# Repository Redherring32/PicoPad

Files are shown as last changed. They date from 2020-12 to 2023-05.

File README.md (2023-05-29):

# PicoPad
The world's smallest functional NES controller

## Repository Structure:
* Board Files: Contains all files necessary to open the project in KiCad, as well as the schematic and schematic symbols

* 3D-CAD: Contains the source CAD files for the housing design

* PicoPad.pretty: Library of all the custom footprints used on the board

PicoPad

## License:
Licensed under the TAPR Open Hardware License (www.tapr.org/OHL)

©Redherring32 2020

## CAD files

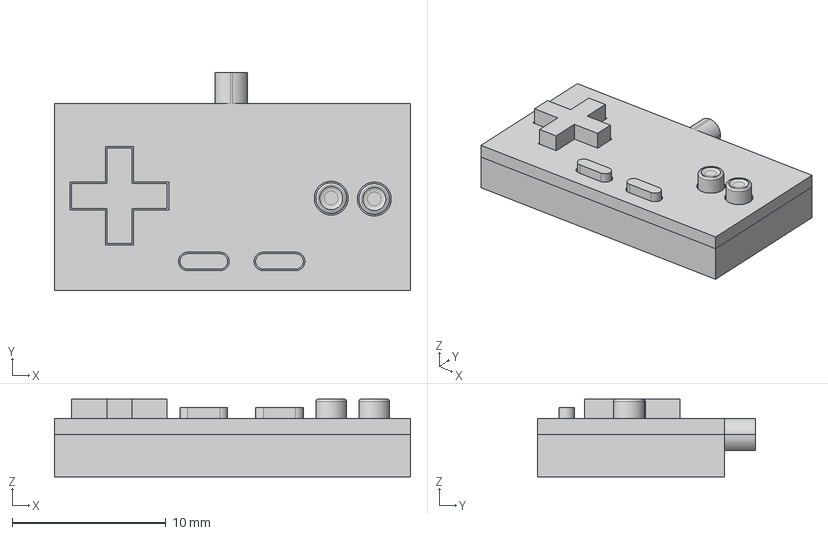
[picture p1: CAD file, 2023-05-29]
3D-CAD/PicoPad Shell.step
23.1 x 14.2 x 5.05 mm

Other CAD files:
3D-CAD/PicoPad Shell.f3z

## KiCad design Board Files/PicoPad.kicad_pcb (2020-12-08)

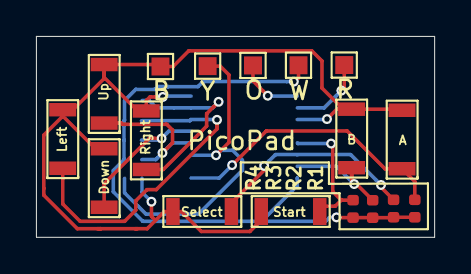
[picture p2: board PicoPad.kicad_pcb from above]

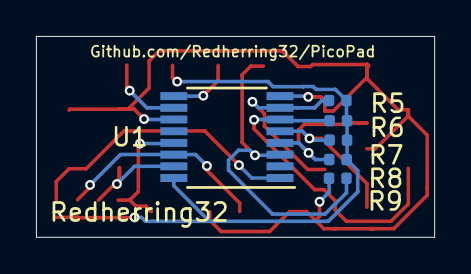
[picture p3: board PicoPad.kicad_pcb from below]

Board: 2 copper layers, 22.1 x 11.2 mm, 23 parts (6 on the bottom side), 13 nets.

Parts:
A1: SW_Push; MiniSwitch
B1: SW_Push; MiniSwitch
Brown1: TestPoint_Pad_1.0x1.0mm
D1: SW_Push; MiniSwitch
L1: SW_Push; MiniSwitch
Orange1: TestPoint_Pad_1.0x1.0mm
R1, R2, R3, R4, R5, R6, R7, R8, R9: 1K; R_0402_1005Metric
Red1: TestPoint_Pad_1.0x1.0mm
Right1: SW_Push; MiniSwitch
SL1: SW_Push; MiniSwitch
ST1: SW_Push; MiniSwitch
U1: CD4021BE; TSSOP-16_4.4x5mm_P0.65mm
U2: SW_Push; MiniSwitch
White1: TestPoint_Pad_1.0x1.0mm
Yellow1: TestPoint_Pad_1.0x1.0mm

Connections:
/5V: R1.1, R2.1, R3.1, R4.1, R5.1, R6.1, R7.1, R8.1, U1.16, White1.1
/Clock: Red1.1, U1.10
/Data: R9.1, U1.3, Yellow1.1
/GND: A1.1, B1.1, Brown1.1, D1.1, L1.1, R9.2, Right1.1, SL1.1, ST1.1, U1.8, U1.11, U2.1
/Strobe: Orange1.1, U1.9
unnamed: A1.2, R1.2, U1.1
unnamed: B1.2, R3.2, U1.15
unnamed: D1.2, R7.2, U1.5
unnamed: L1.2, R6.2, U1.6
unnamed: R2.2, SL1.2, U1.14
unnamed: R4.2, ST1.2, U1.13
unnamed: R8.2, U1.4, U2.2
unnamed: R5.2, Right1.2, U1.7

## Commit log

2020-12-08 Cleaned everything up for release
    [PicoPad.kicad_pcb, PicoPad.sch]
2020-12-09 Add labels to schematic
    [PicoPad.sch]
2023-05-29 + Added Housing CAD!
    [PicoPad Shell.f3z, PicoPad Shell.step]
